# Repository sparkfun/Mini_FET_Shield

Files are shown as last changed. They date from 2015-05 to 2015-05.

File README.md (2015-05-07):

SparkFun Mini FET Shield
========================================

SparkFun Mini FET Shield

[*SparkFun Mini FET Shield (DEV-09627)*](https://www.sparkfun.com/products/9627)

 Developed by Dave Vondle and IDEO Labs, this board is essentially the same as our Power Driver Shield, but the through-hole parts have been switched out for smaller SMD construction, allowing you to to drive high-current switches with your Arduino Pro Mini. 
 This is a great shield for small prototyping.

 Repository Contents
-------------------

* **/Hardware** - Eagle design files (.brd, .sch)
* **/Production** - Production panel files (.brd)

Documentation
--------------
* **[Hookup Guide](https://learn.sparkfun.com/tutorials/mini-fet-shield-hookup-guide)** - Basic hookup guide for the Mini FET shield.
* **[SparkFun Fritzing repo](https://github.com/sparkfun/Fritzing_Parts)** - Fritzing diagrams for SparkFun products.
* **[SparkFun 3D Model repo](https://github.com/sparkfun/3D_Models)** - 3D models of SparkFun products. 

License Information
-------------------
This product is _**open source**_! 

The **hardware** is released under [Creative Commons ShareAlike 4.0 International](https://creativecommons.org/licenses/by-sa/4.0/).

Please use, reuse, and modify these files as you see fit. Please maintain attribution to SparkFun Electronics and release anything derivative under the same license.

Distributed as-is; no warranty is given.

- Your friends at SparkFun.

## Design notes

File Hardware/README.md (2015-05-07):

SparkFun <PRODUCT NAME> Design Files
=====================================

The .sch and .brd files hare are Eagle CAD schematic and PCB design files from SparkFun Electronics.
A freeware version of Eagle can be found [here](http://www.cadsoftusa.com/download-eagle/freeware/). 

License
---------
This product is open source! 
The hardware is released under [Creative Commons ShareAlike 4.0 International](https://creativecommons.org/licenses/by-sa/4.0/).

Please use, reuse, and modify these files as you see fit. Please maintain attribution to SparkFun Electronics and release anything derivative under the same license.

Distributed as-is; no warranty is given.

- Your friends at SparkFun.

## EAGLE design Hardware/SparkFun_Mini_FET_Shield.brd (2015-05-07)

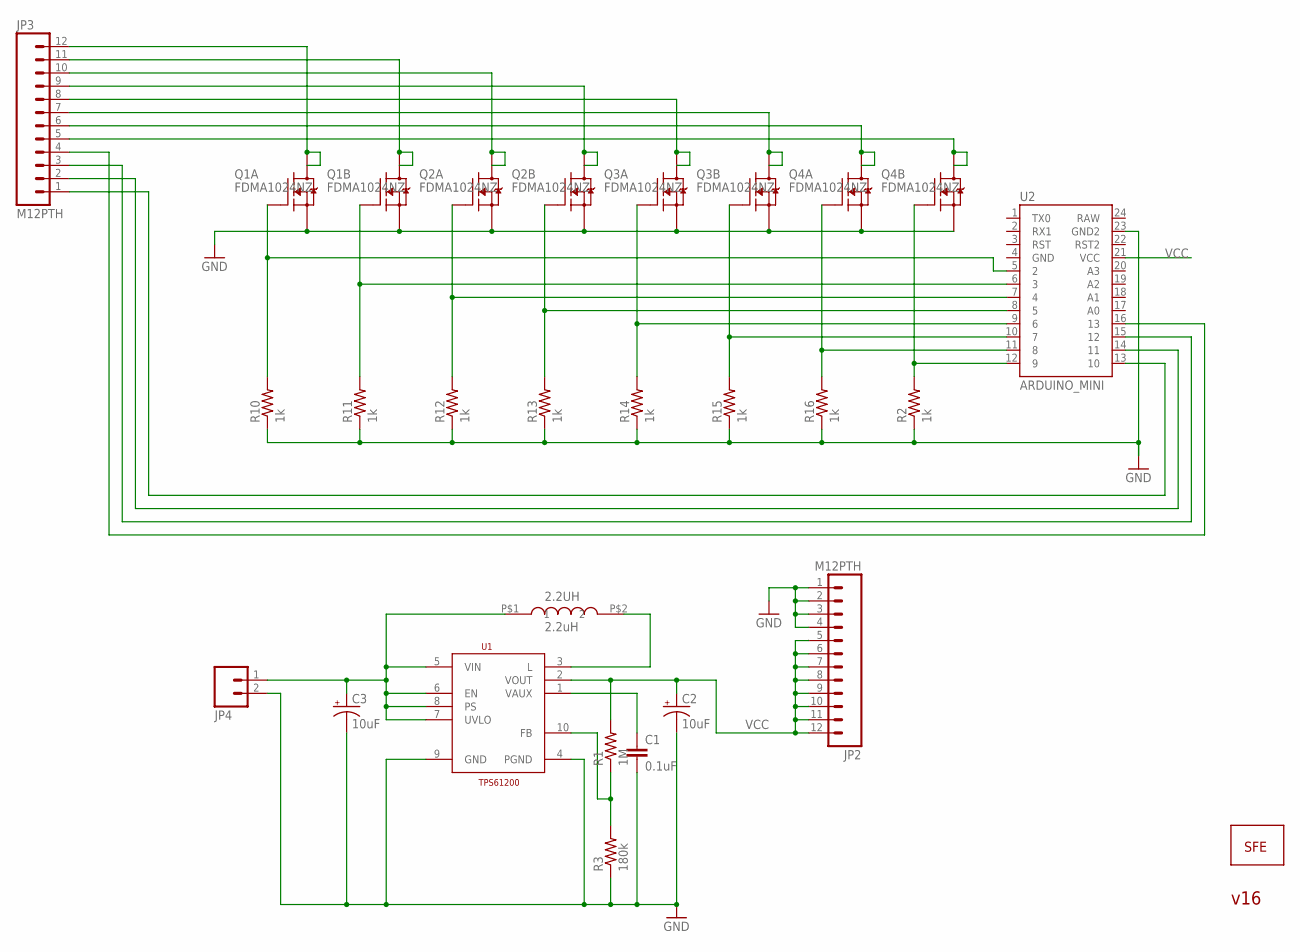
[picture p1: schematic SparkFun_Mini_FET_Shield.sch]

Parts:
2.2UH: 2.2uH; VLF4012A
C1: 0.1uF; 0402-CAP
C2, C3: 10uF; EIA3216
JP2, JP3: M12PTH; 1X12
JP4: M02PTH; 1X02
JP5: LOGO-SFESK; SFE-LOGO-FLAME
Q1, Q2, Q3, Q4: FDMA1024NZ; MICROFET_2X2
R1: 1M; 0402-RES
R2, R10, R11, R12, R13, R14, R15, R16: 1k; 0402-RES
R3: 180k; 0402-RES
U1: TPS61200; DRC-S-PVSON-N10
U2: ARDUINO_MINI

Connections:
GND: C1.2, C2.C (-), C3.C (-), JP2.1, JP2.2, JP2.3, JP2.4, JP4.2, Q1.S1 (S), Q1.S2 (S), Q2.S1 (S), Q2.S2 (S), Q3.S1 (S), Q3.S2 (S), Q4.S1 (S), Q4.S2 (S), R2.1, R3.1, R10.1, R11.1, R12.1, R13.1, R14.1, R15.1, R16.1, U1.4 (PGND), U1.9 (GND), U2.23 (GND2)
unnamed: JP3.4, U2.16 (13)
unnamed: R1.1, R3.2, U1.10 (FB)
unnamed: C1.1, U1.1 (VAUX)
unnamed: 2.2UH.P$2 (2), U1.3 (L)
unnamed: Q1.G1 (G), R10.2, U2.5 (2)
unnamed: 2.2UH.P$1 (1), C3.A (+), JP4.1, U1.5 (VIN), U1.6 (EN), U1.7 (UVLO), U1.8 (PS)
unnamed: Q1.G2 (G), R11.2, U2.6 (3)
unnamed: Q2.G1 (G), R12.2, U2.7 (4)
unnamed: Q2.G2 (G), R13.2, U2.8 (5)
unnamed: Q3.G1 (G), R14.2, U2.9 (6)
unnamed: Q3.G2 (G), R15.2, U2.10 (7)
unnamed: Q4.G1 (G), R16.2, U2.11 (8)
unnamed: Q4.G2 (G), R2.2, U2.12 (9)
unnamed: JP3.12, Q1.D1 (D), Q1.D1_2 (D1)
unnamed: JP3.11, Q1.D2 (D), Q1.D2_2 (D1)
unnamed: JP3.10, Q2.D1 (D), Q2.D1_2 (D1)
unnamed: JP3.9, Q2.D2 (D), Q2.D2_2 (D1)
unnamed: JP3.8, Q3.D1 (D), Q3.D1_2 (D1)
unnamed: JP3.7, Q3.D2 (D), Q3.D2_2 (D1)
unnamed: JP3.6, Q4.D1 (D), Q4.D1_2 (D1)
unnamed: JP3.5, Q4.D2 (D), Q4.D2_2 (D1)
unnamed: JP3.3, U2.15 (12)
unnamed: JP3.2, U2.14 (11)
unnamed: JP3.1, U2.13 (10)
VCC: C2.A (+), JP2.5, JP2.6, JP2.7, JP2.8, JP2.9, JP2.10, JP2.11, JP2.12, R1.2, U1.2 (VOUT), U2.21 (VCC)

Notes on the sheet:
v16

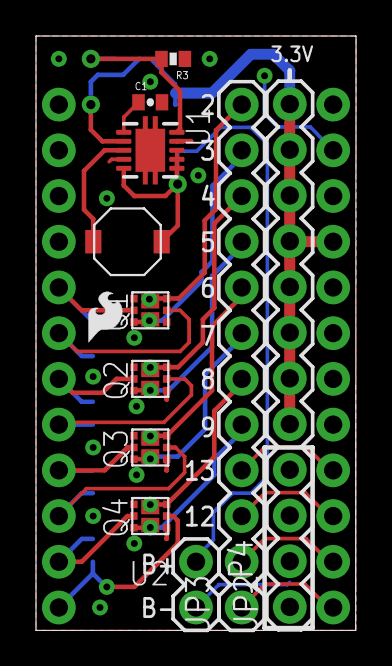
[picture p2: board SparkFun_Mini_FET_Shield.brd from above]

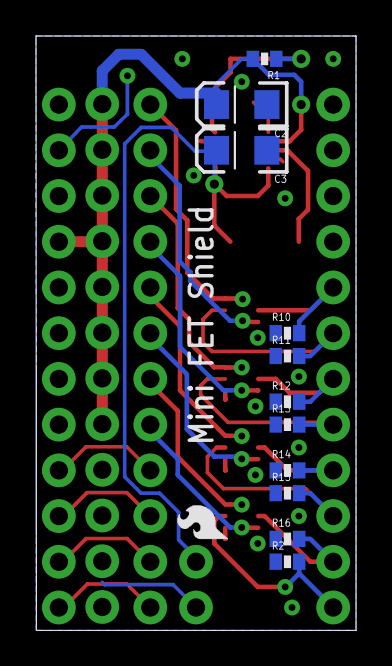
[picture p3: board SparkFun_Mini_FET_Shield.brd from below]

Board: 2 copper layers, 17.8 x 33.0 mm, 25 parts (12 on the bottom side), 26 nets.

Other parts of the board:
JP1: LOGO-SFESK; SFE-LOGO-FLAME
